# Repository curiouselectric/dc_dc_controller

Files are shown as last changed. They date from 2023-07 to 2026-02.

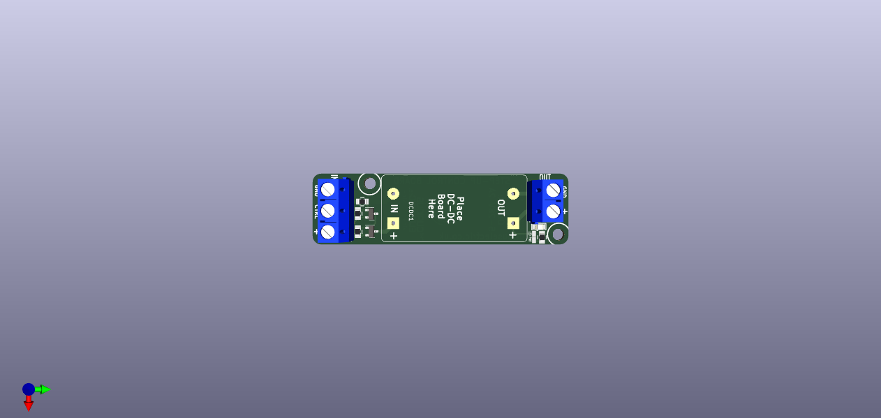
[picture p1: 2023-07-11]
DC_DC_Controller Instructions/Photos/DC_DC_Controller.png

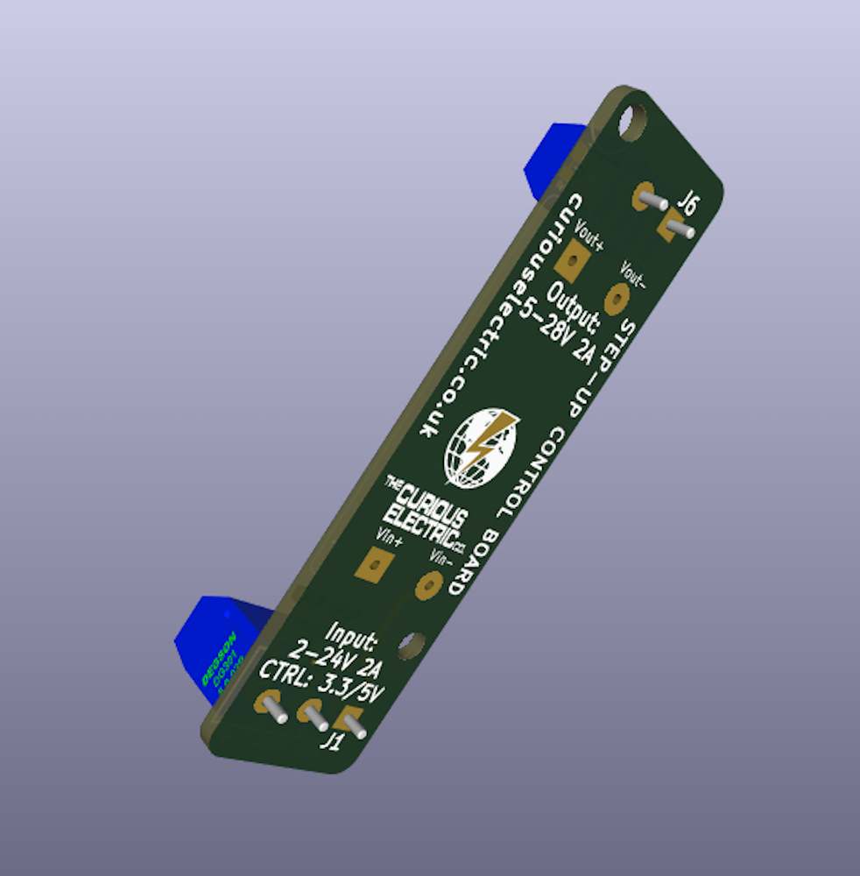
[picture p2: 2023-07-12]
DC_DC_Controller Instructions/Photos/Photos for Tindie/DC_DC_Controller 2.png

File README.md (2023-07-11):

# dc_dc_controller
A logic controlled DC-DC step up converter PCB

Have you needed to power a small sensor with 12 or 24V but only had 3.3V or 5V available?
Maybe you need to really reduce your power consumption and running the sensor all the time will consume too much power?
Then this simple logic-controller DC-DC step-up converter might be useful for you!

The step-up converter is an off-the-shelf DC-DC converter board using the MT3608. This can take an input voltage of 2-24V DC and supply an output voltage up to 28V DC. Up to 2A can be supplied (but not recommended for any length of time).

While this converter is useful, what if you only want to check your sensor every 10 mins or hour? Keeping the sensor powered up with a DC-DC converter will just waste energy, which might be in short supply from a battery-based system. So, we added a MOSFET based logic-controlled switch. You apply 3.3V - 5V to the control input and it will switch on the DC-DC converter. Your device can wake up, check your sensor, then go back to sleep and save lots of energy.

We have used this circuit for a weather monitoring station.

This is a reasonably simple kit which requires a small amount of soldering.
It should take under 1 hour to build.
Not suitable for under 12 years old.

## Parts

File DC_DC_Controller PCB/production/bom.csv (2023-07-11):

Designator | Footprint | Quantity | Value | LCSC Part #
D1 | SM0805_LED | 1 | LED | C84256
DCDC1 | TH_DCDC_Step_up_MT3608 | 1 | DC-DC_GENERIC
J1 | SIL-3_screw_terminal | 1 | IN
J2 | PCB_DC_DC_Outline_v1 | 1 | PCB
J3 | 2019_011_16_CuriousElectricCompany_Logo_Round_Logo_No_words_KiCAD_10mm_PCBLogo | 1 | LOGO
J4 | TCEC_Words_13mm | 1 | LOGO_2
J5 | SIL-2_solder_connect_2 | 1 | LED PWR
J6 | SIL-2_screw_terminal | 1 | OUT
Q1 | SOT-23 | 1 | 2N7002 | C8545
Q2 | SOT-23 | 1 | PMV48XP | C2959854
R1, R2 | SM0805 | 2 | 100k | C103905
R3, R4 | SM0805 | 2 | 1k | C103903

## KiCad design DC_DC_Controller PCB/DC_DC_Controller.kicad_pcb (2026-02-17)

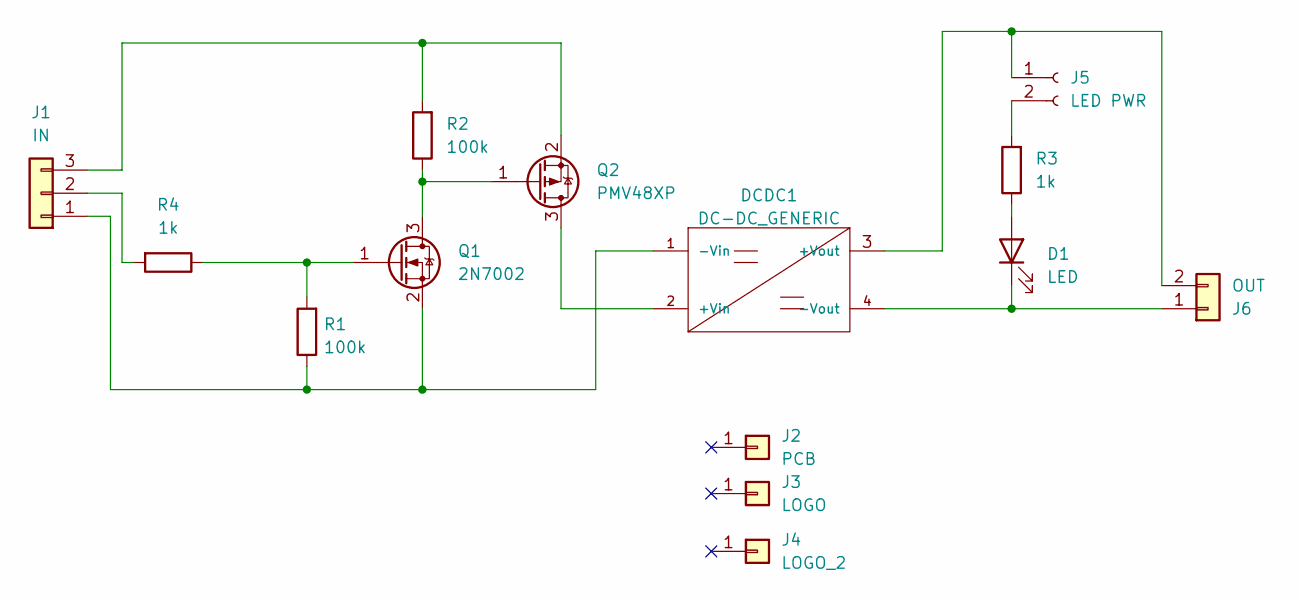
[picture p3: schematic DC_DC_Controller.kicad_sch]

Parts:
D1: LED; SM0805_LED; LCSC C84256
DCDC1: DC-DC_GENERIC; TH_DCDC_Step_up_MT3608
J1: IN; SIL-3_screw_terminal
J2: PCB; PCB_DC_DC_Outline_v1
J3: LOGO; 2019_011_16_CuriousElectricCompany_Logo_Round_Logo_No_words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
J4: LOGO_2; TCEC_Words_13mm
J5: LED PWR; SIL-2_solder_connect_2
J6: OUT; SIL-2_screw_terminal
Q1: 2N7002; SOT-23; LCSC C8545
Q2: PMV48XP; SOT-23; LCSC C2959854
R1, R2: 100k; SM0805; JLCPCB Add Y
R3, R4: 1k; SM0805; JLCPCB Add Y

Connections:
unnamed: D1.1 (K), DCDC1.4 (-Vout), J6.1
unnamed: D1.2 (A), R3.1
unnamed: DCDC1.1 (-Vin), J1.1, Q1.2 (S), R1.1
unnamed: DCDC1.2 (+Vin), Q2.3 (D)
unnamed: DCDC1.3 (+Vout), J5.1, J6.2
unnamed: J1.2, R4.2
unnamed: J1.3, Q2.2 (S), R2.2
unnamed: J5.2, R3.2
unnamed: Q1.1 (G), R1.2, R4.1
unnamed: Q1.3 (D), Q2.1 (G), R2.1

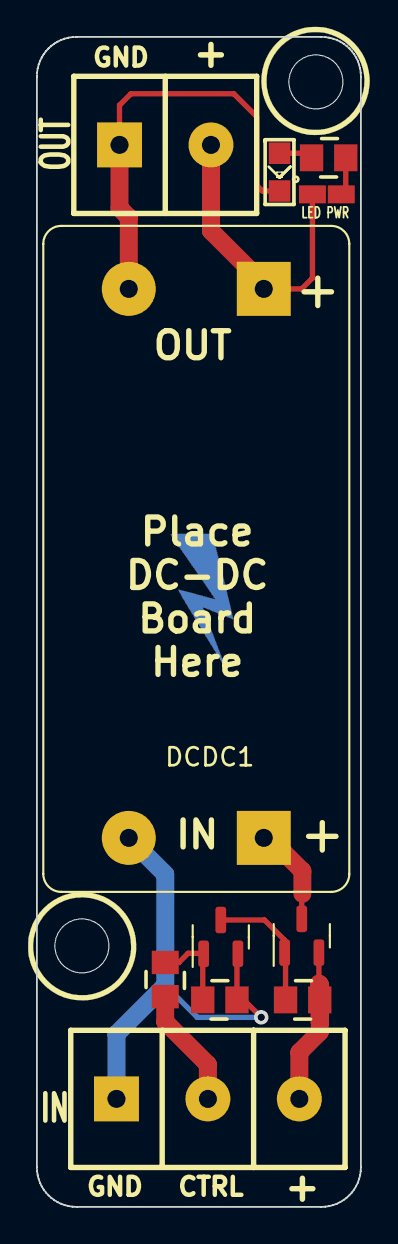
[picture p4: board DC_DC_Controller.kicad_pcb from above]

Board: 2 copper layers, 18.0 x 65.0 mm, 14 parts (1 on the bottom side), 10 nets.

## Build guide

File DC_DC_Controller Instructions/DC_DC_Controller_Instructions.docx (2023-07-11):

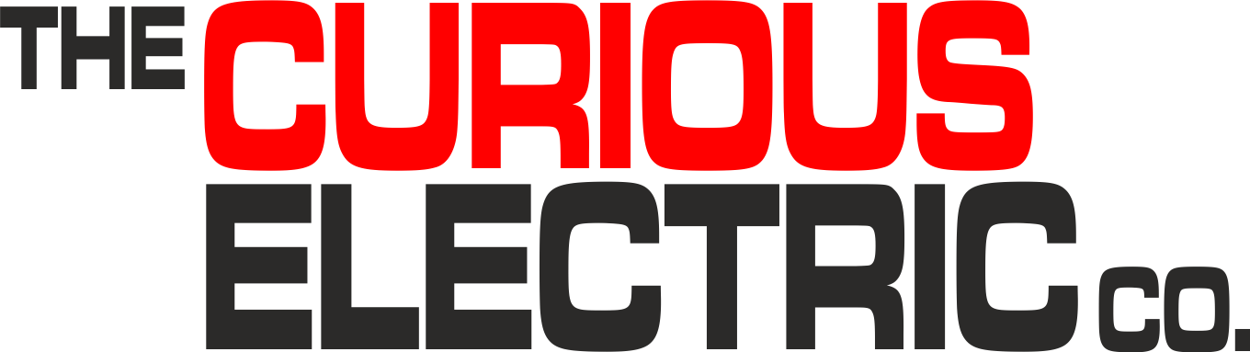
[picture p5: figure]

| DC-DC Controller Instructions

Date: | 11/07/2023 | Version: | 1.0 | By: | Matt Little

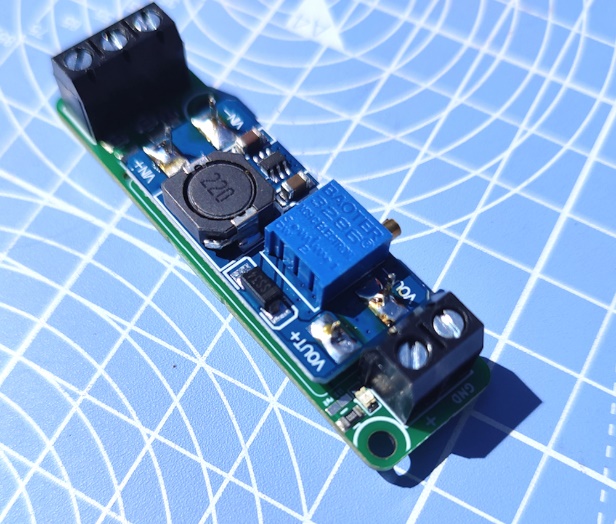
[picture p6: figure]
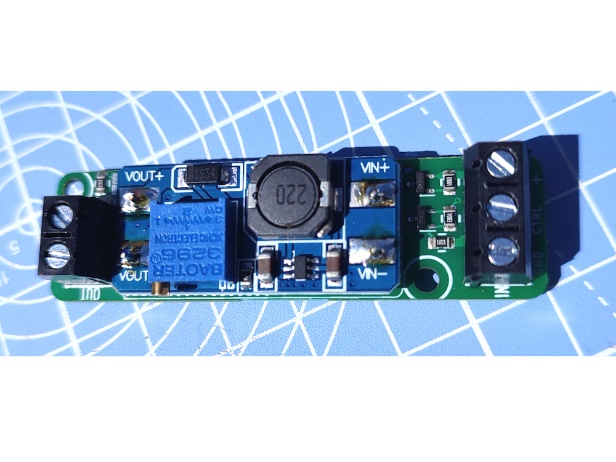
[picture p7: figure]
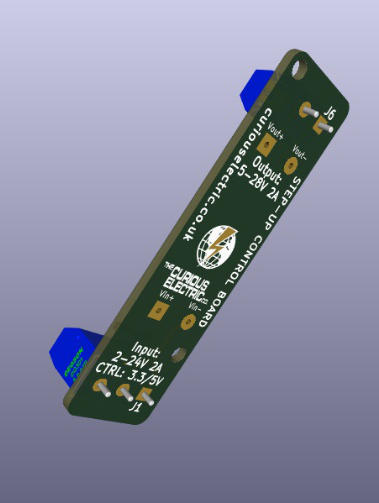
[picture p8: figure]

Have you needed to power a small sensor with 12 or 24V but only had 3.3V or 5V available?

Maybe you need to really reduce your power consumption and running the sensor all the time will consume too much power?

Then this simple logic-controller DC-DC step-up converter might be useful for you!

The step-up converter is an off-the-shelf DC-DC converter board using the MT3608. This can take an input voltage of 2-24V DC and supply an output voltage up to 28V DC. Up to 2A can be supplied (but not recommended for any length of time).

While this converter is useful, what if you only want to check your sensor every 10 mins or hour? Keeping the sensor powered up with a DC-DC converter will just waste energy, which might be in short supply from a battery-based system. So, we added a MOSFET based logic-controlled switch. You apply 3.3V - 5V to the control input and it will switch on the DC-DC converter. Your device can wake up, check your sensor, then go back to sleep and save lots of energy.

We have used this circuit for a weather monitoring station.

This is a reasonably simple kit which requires a small amount of soldering.

It should take under 1 hour to build.

Not suitable for under 12 years old.

# Parts included:

| | | DC-DC converter PCB (pre-built MT3608)

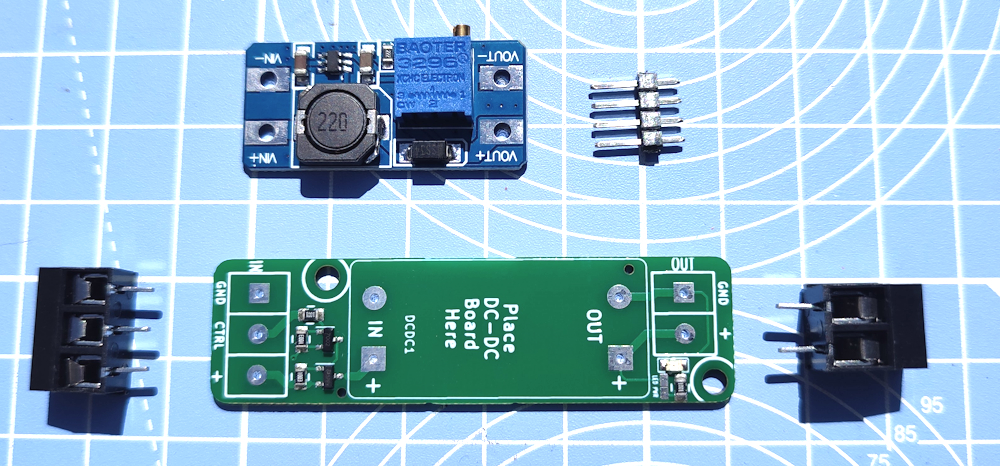
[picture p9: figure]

| | | | | | | 4 way pin header
| | | | | | | Output Terminals (2 way)
Input Terminals (3-way)
| | Main PCB

# PCB Parts List:

Ref | Item | Quantity
PCB | Main PCB with pre-assembled SMD | 1
DCDC | DC-DC converter PCB pre-built MT3608 | 1
IN | 3-way terminal block | 1
OUT | 2-way terminal block | 1
PIN | 4-way pin header | 1

# Tools required:

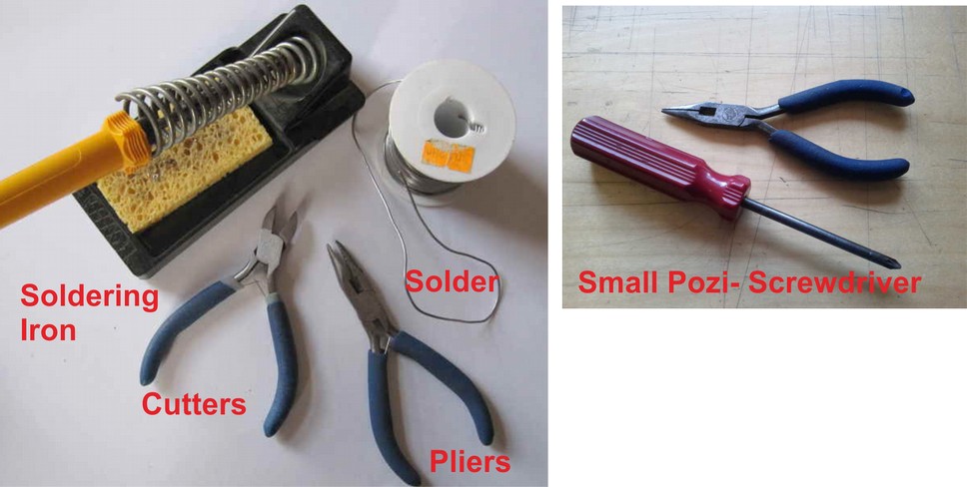
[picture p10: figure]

| | Long-nosed Pliers
Soldering Iron | | Posi-drive Screwdriver
Solder
Side cutters
Scissors (not shown)

# Instructions:

Step: 1 | Fit pins to main PCB

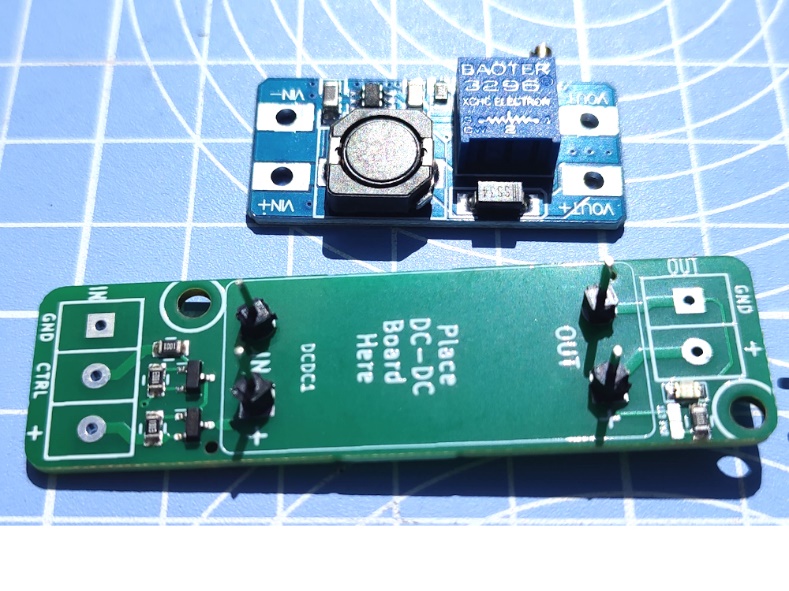
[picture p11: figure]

| | Cut the four head pins into single pins with a pair of side cutters. One pin goes into each of the four holes within the DC-DC Board outline on the main PCB. Solder the pins in place on the underside of the main PCB.

Step: 2 | Solder DC-DC converter PCB to main PCB

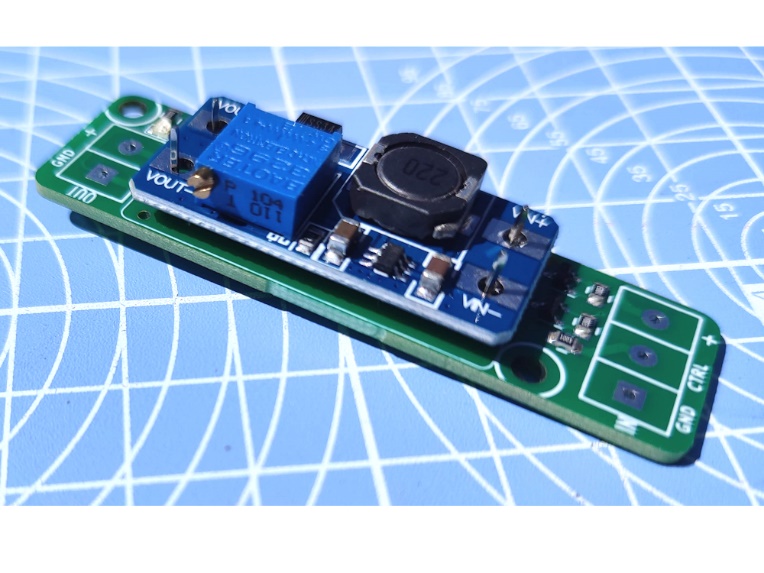
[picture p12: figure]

Carefully align the DC-DC converter PCB with the pins just soldered. Double check that it has the correct orientation – the IN + and IN – should align with VIN+ and VIN-. The OUT pins should align with the VOUT+ and VOUT- pins. Push the DC-DC PCB down until it rests on the header pin spacers. Solder on the top of the DC-DC PCB on each of the four pins.

Step: 3 | Add the input and output terminals

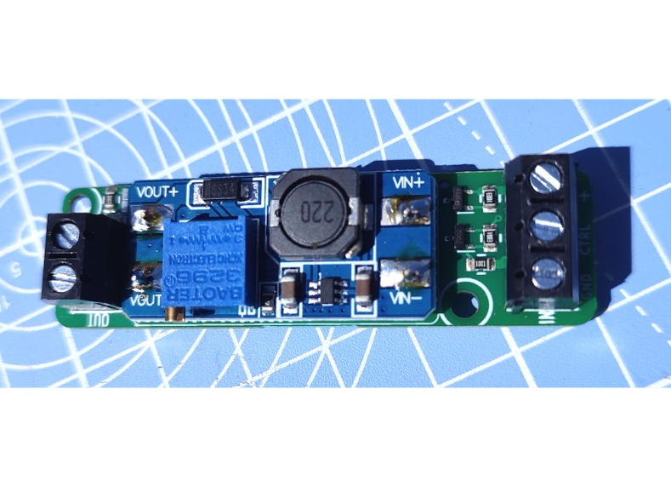
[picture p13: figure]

| | Use the 2-way terminal block for the output. Check that the openings for the wires are facing away from the PCB, so that the cables can be inserted. Solder the terminal block in place. Use the 3-way terminal black for the input. Again, check the openings face away from the PCB. Solder the terminal block in place.

Step: 4 | Connect the LED (if required)

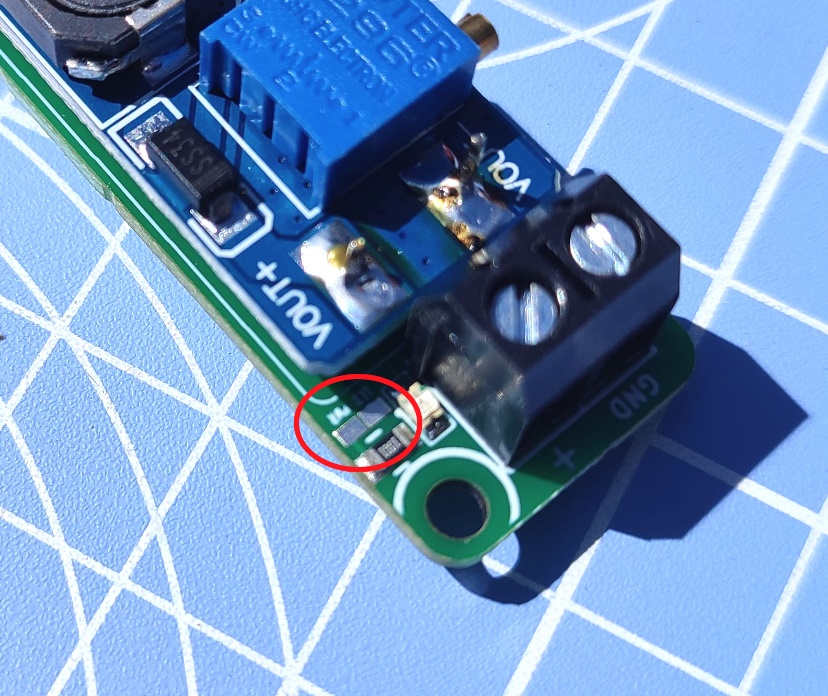
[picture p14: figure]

This step is optional. The default is that there will NOT be an LED to show power is on. If you would like an output power indicator LED, then please add a blob of solder to join the two pads circled in red and labelled “LED_PWR”. This will connect the red LED onto the output power pins. This LED is quite bright and due to the DC-DC converter efficiency, consumes about 40mA from the input when switched on. This is OK for short pulses, but for any length of time then this might

Step: 5 | PCB is finished!

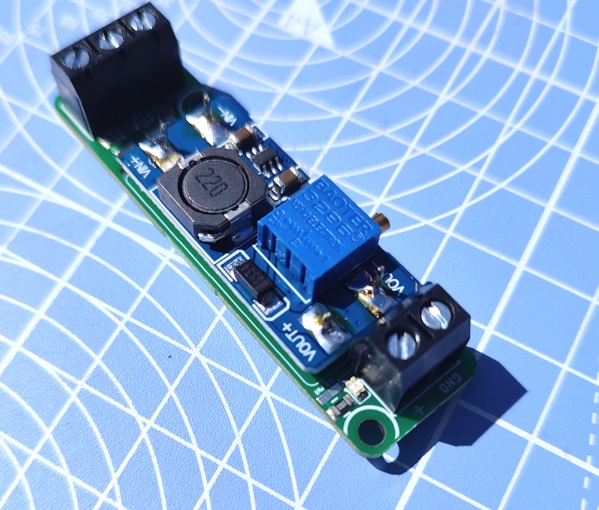
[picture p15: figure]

Have a nice cup of tea!

You are now ready to try it out!

Apply a voltage to the input. Use a low voltage, maybe 3.3V or 5V.

The input terminals are:

GND : 0V

CTRL : This is the control pin. You can use the input voltage here, or 3.3V or 5V logic.

+ : This is the input voltage, from 2V to 24V DC.

Without connection to the CTRL then the unit will be off.

Apply a voltage to the CTRL terminal. This will switch on the DC-DC converter, and you should read a voltage on the output pins. Use a multi-meter to read this voltage. Adjust the small variable resistor (gold-coloured knob on the blue potentiometer). This will adjust the output voltage. Adjust this until you have the correct output voltage.

Once set, I use a small amount of nail varnish to lock the gold-coloured knob in position.

If you have added the LED_PWR connection then the LED on the unit should be lit.

# Testing & Fault Finding

Any issues at all then try the following:

- Check soldering.
- Check power connections.

# Design Files

These can be found, along with these instructions, in the repository here:

https://github.com/curiouselectric/dc_dc_controller

# Contact details:

This kit has been designed and produced by:

The Curious Electric Company

hello@curiouselectric.co.uk

www.curiouselectric.co.uk

We would like you to be happy with this kit. If you are not happy for any reason, then please contact us and we will help to sort it out.

Please email hello@curiouselectric.co.uk with any questions or comments.

Please tweet us at @curiouselectric

If any parts are missing from your kit, then please email hello@curiouselectric.co.uk with details, including where the kit was purchased.

More information can be found via www.curiouselectric.co.uk

# Circuit Schematic:

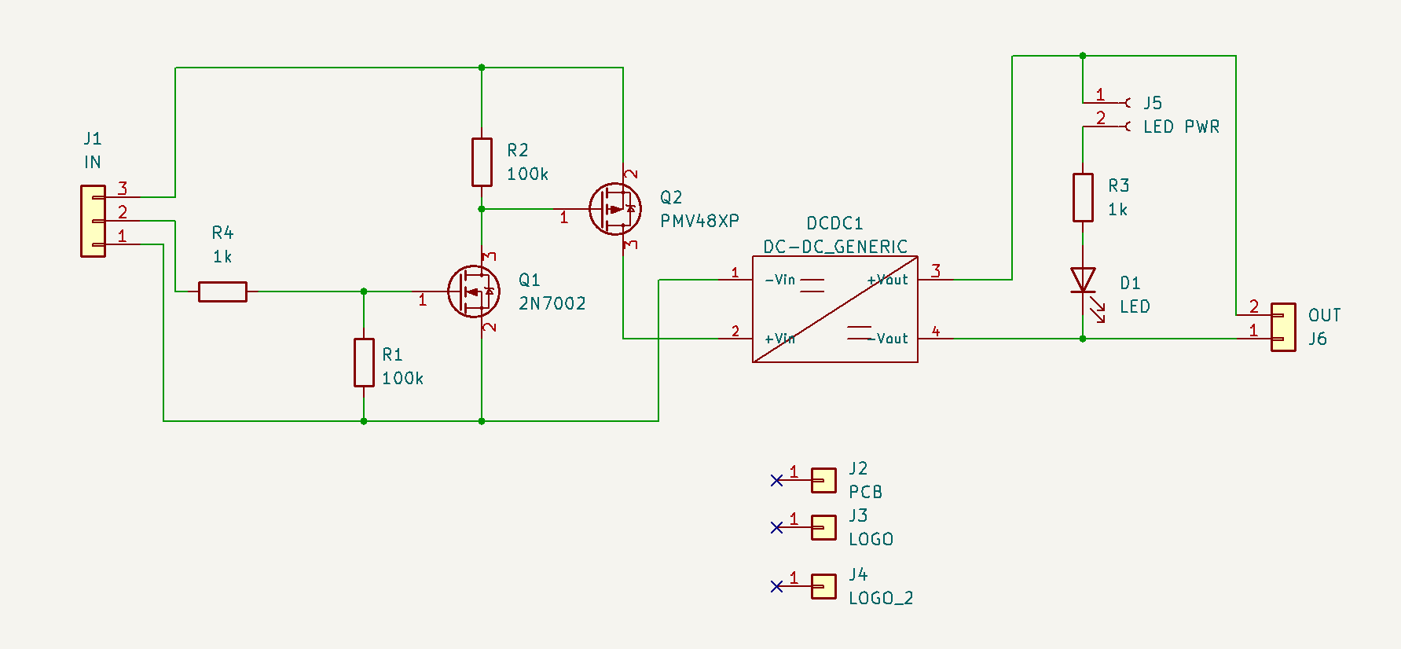
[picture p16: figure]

# PCB:

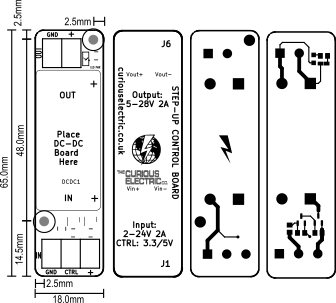
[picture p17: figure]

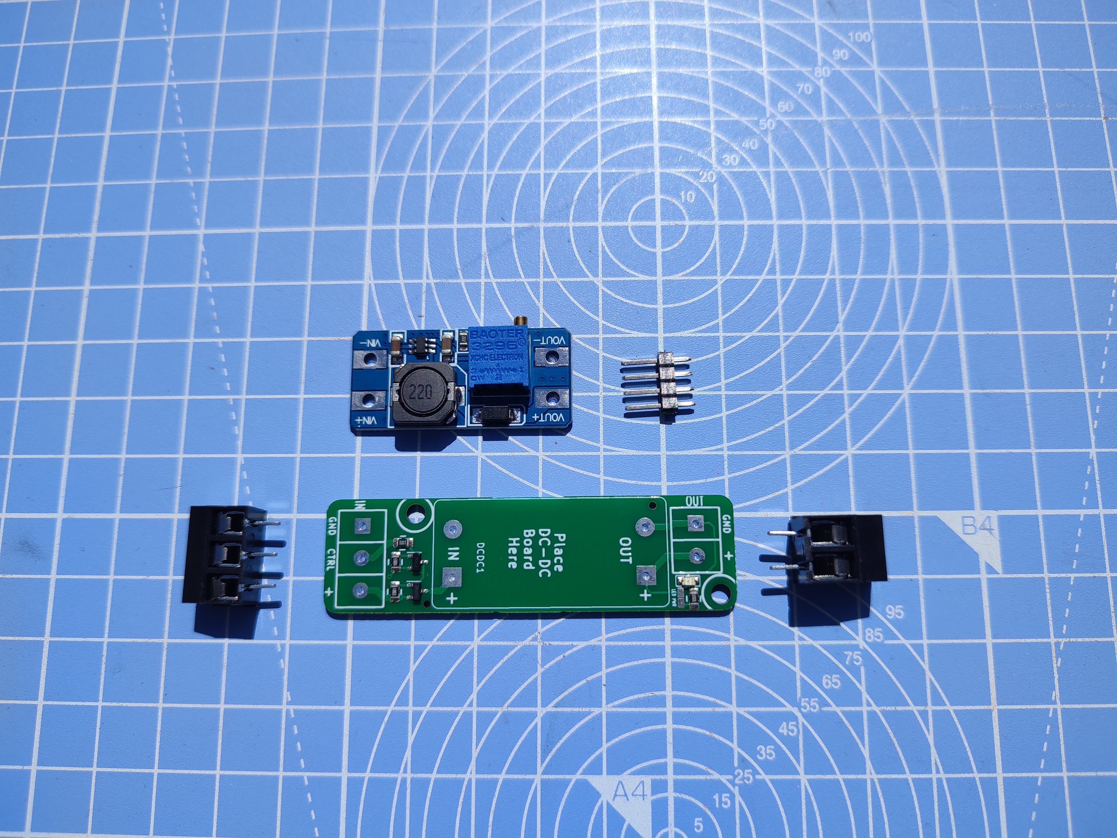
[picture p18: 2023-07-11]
DC_DC_Controller Instructions/Photos/IMG_20230703_141917.jpg

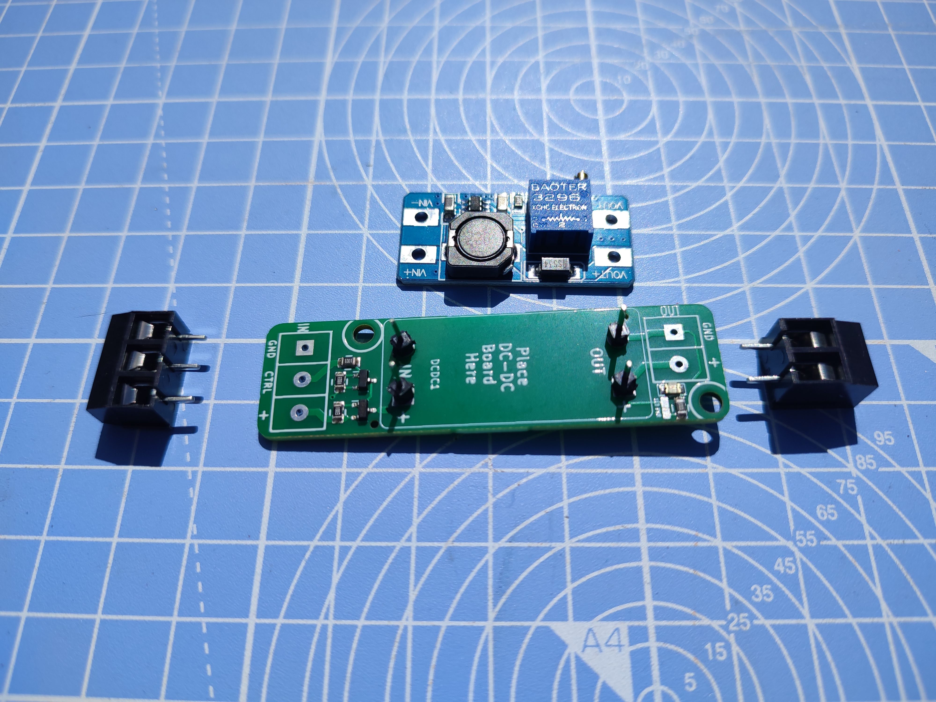
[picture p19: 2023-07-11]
DC_DC_Controller Instructions/Photos/IMG_20230703_142104.jpg

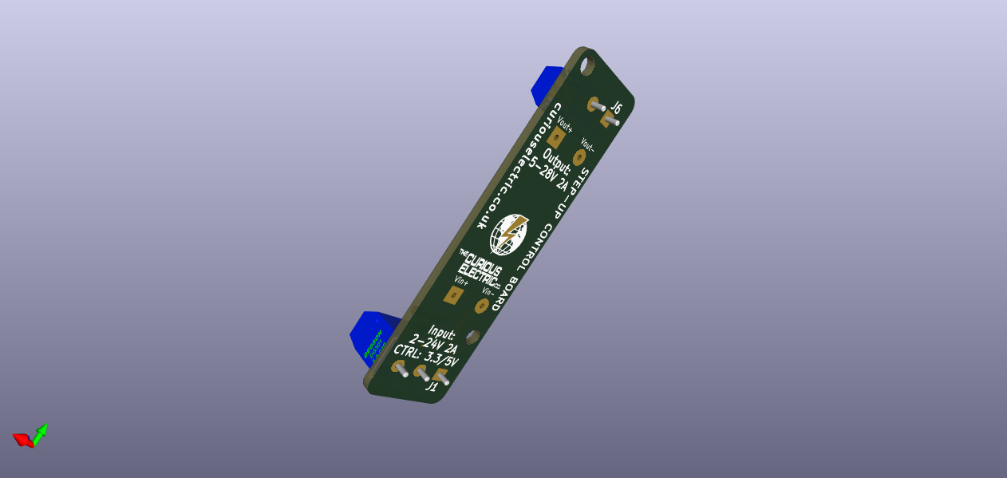
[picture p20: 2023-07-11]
DC_DC_Controller Instructions/Photos/DC_DC_Controller 2.png

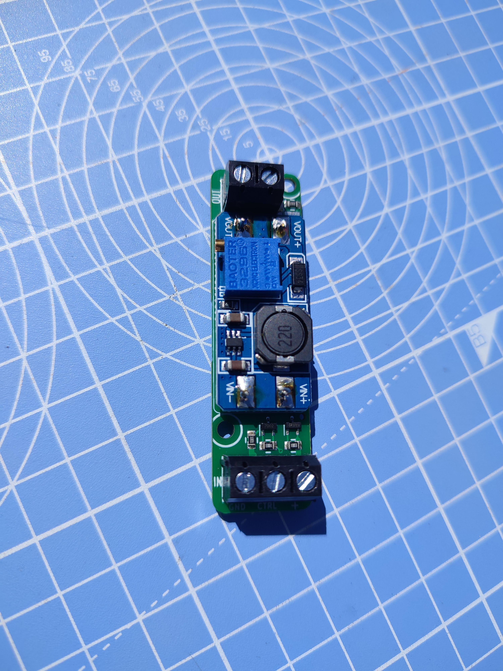
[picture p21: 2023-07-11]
DC_DC_Controller Instructions/Photos/IMG_20230703_142442.jpg
